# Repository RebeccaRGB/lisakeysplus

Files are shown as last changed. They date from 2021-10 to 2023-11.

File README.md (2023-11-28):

# LisaKeysPlus
This repository contains a project to create a modern replacement PCB for Apple Lisa keyboards.

The Apple Lisa used a Keytronic foam and foil keyboard which is notorious for the foam turning to dust rendering the keyboard unusable. Even after replacing the foam, I was unable to get my Lisa keyboard fully working, so instead I created a replacement PCB so I could use modern keyswitches.

This repository is still a work in progress. The timing on the keyboard controller code still needs adjusting, and the PCB may require further revisions. For example, I only recently added stabilizers to the board. If you downloaded the PCB designs before 28 November 2023, you will want to download them again to get stabilizers and a better fitting PCB. Otherwise your keys won't be stable and you'll need to expand some of the holes with a Dremel.

## Stuff To Get
* 76x Cherry MX compatible keyswitches
* 76x through-hole 1N4148 diodes
* 1x through-hole 3mm LED
* 1x through-hole 150 ohm resistor
* 2x through-hole 3-pin 2.54mm-spacing male headers
* 2x through-hole 14-pin 2.54mm-spacing male headers
* 1x through-hole 5-pin 2.54mm-spacing male header
* 1x Adafruit ItsyBitsy 32u4 5V microcontroller
* 1x 2-pin jumper
* 6x 2u stabilizers
* 1x 6.5u stabilizer (good luck; you will most likely need to get a 7u stabilizer and shorten it)

## Stuff to Make
* 1x keyboard matrix PCB, made from the Gerber files in the `gerber` directory
* 4x mounting brackets, 3D printed from the STL file in the `mounting-bracket` directory
* a set of keycaps, made from the templates in the `keycaps` directory (more details needed)
    * The hardest to get will be the 6.5u spacebar and the 1.5u backspace. Max Keyboards will make custom sets with a 6.5u spacebar. I haven't found a source for 1.5u backspace yet. You can use a 1.5u backslash key, but the profile will be wrong.
    * You will need a 1u backslash key.
    * The 1.75u return key can be made from a 1.75u caps lock key.
    * You will need two 2.25u shift keys instead of a 2.25u shift key and a 2.75u shift key.
    * For the bottom row, in addition to the 6.5u spacebar, you will need two 1u option keys, a 2u command key, and a 2u enter key. (The original keyboard had 1.5u command and enter keys and a 7.5u spacebar, but I shortened the spacebar to at least something obtainable.)
    * Instead of num lock, /, *, -, and 2u tall +, the Lisa has clear, -, +, *, /, and comma, all 1u. Additionally, the +, *, /, and comma keys have a unique style of directional arrows on the bottom half of the key.

## Stuff to Do
* Program the ItsyBitsy microcontroller with the Arduino sketch in the `lisakeysplus` directory
* Solder in the diodes **first**
* Solder in the LED in the desired location near the caps lock key
* Solder in the resistor and headers
* Solder in the ItsyBitsy microcontroller
* Solder in the keyswitches **last**
* Add the jumper between VCC and TIP on the header above the microcontroller
* Attach the stabilizers
* Install the keycaps
* Install the four mounting brackets in the bottom of the keyboard case
* Attach the keyboard cable to the header on the top left of the board
* Assemble the keyboard case

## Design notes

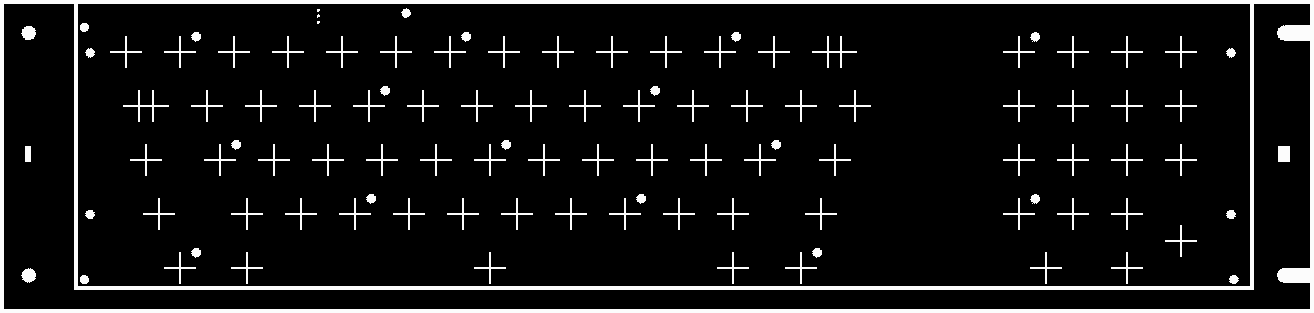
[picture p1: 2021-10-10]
fritzing/LisaKeysPlusI.png

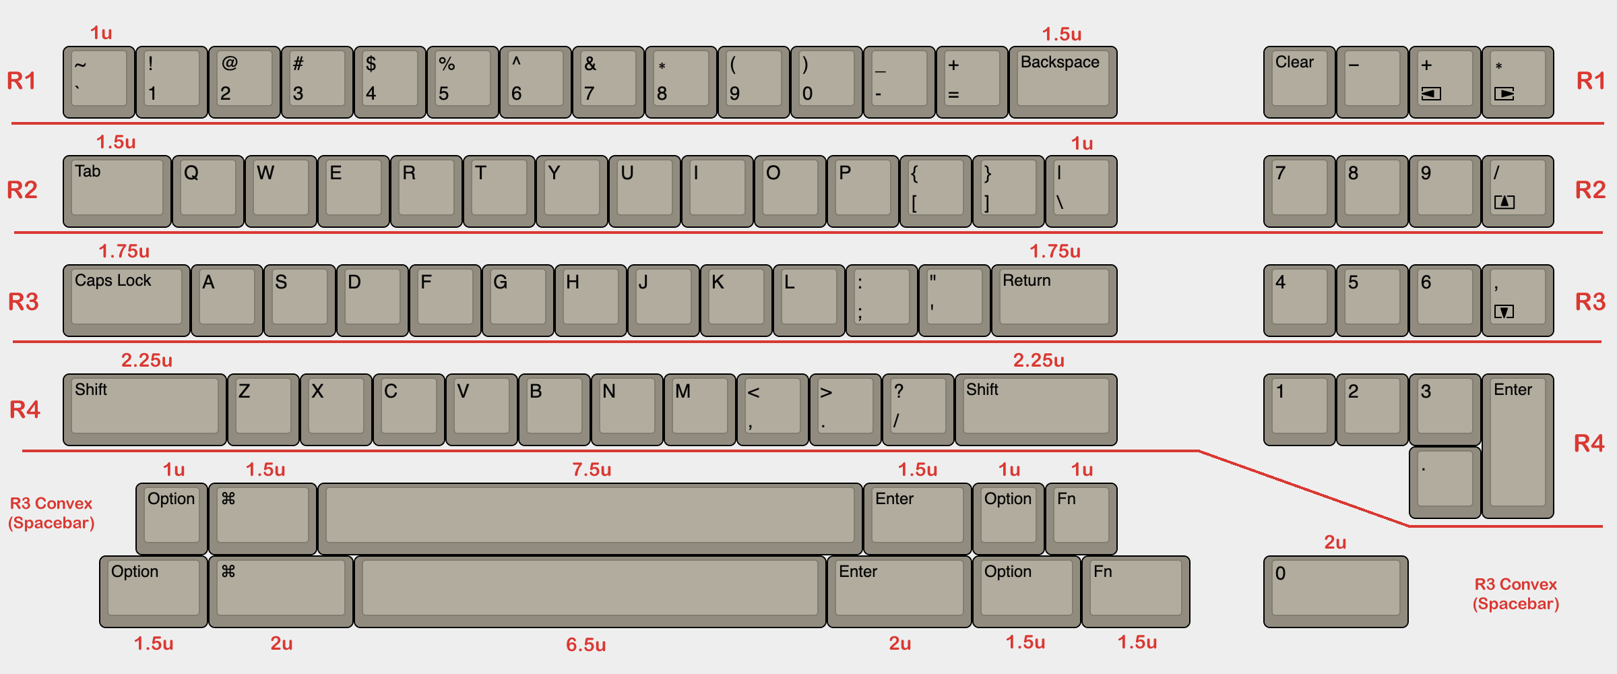
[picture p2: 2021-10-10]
keycaps/Lisa-keycaps.png

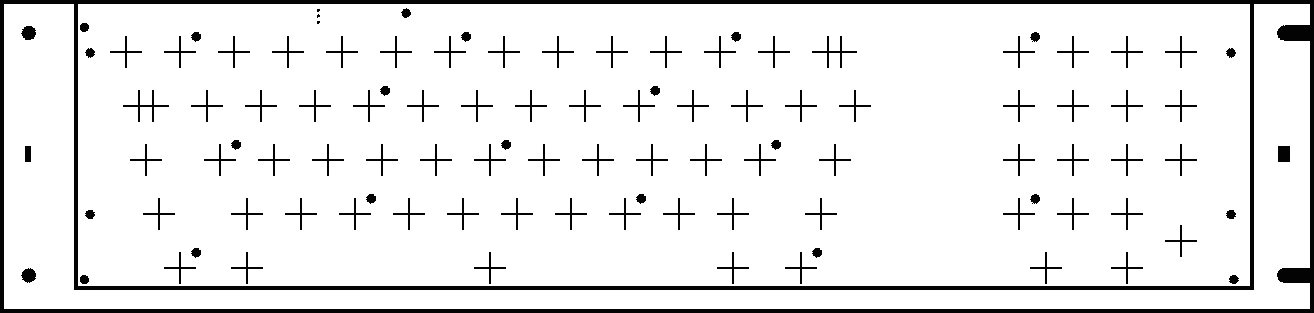
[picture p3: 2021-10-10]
fritzing/LisaKeysPlus.png

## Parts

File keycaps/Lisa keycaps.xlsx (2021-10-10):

Row | Size | Top | Bot | SP
R1 | 1u | ~ | ` | Dual R1C16 ~ `
R1 | 1u | ! | 1 | Dual R1C1 ! 1
R1 | 1u | @ | 2 | Dual R1C2 @ 2
R1 | 1u | # | 3 | Dual R1C3 # 3
R1 | 1u | $ | 4 | Dual R1C4 $ 4
R1 | 1u | % | 5 | Dual R1C5 % 5
R1 | 1u | ^ | 6 | Dual R1C6 ^ 6
R1 | 1u | & | 7 | Dual R1C7 & 7
R1 | 1u | * | 8 | Dual R1C8 * 8
R1 | 1u | ( | 9 | Dual R1C9 ( 9
R1 | 1u | ) | 0 | Dual R1C10 ) 0
R1 | 1u | _ | - | Dual R1C11 _ -
R1 | 1u | + | = | Dual R1C12 + =
R1 | 1.5u | Backspace |  | Text BACKSPACE
R2 | 1.5u | Tab |  | Text TAB
R2 | 1u | Q |  | Mono 5J
R2 | 1u | W |  | Mono 5P
R2 | 1u | E |  | Mono 4O
R2 | 1u | R |  | Mono 5K
R2 | 1u | T |  | Mono 5M
R2 | 1u | Y |  | Mono 6A
R2 | 1u | U |  | Mono 5N
R2 | 1u | I |  | Mono 5B
R2 | 1u | O |  | Mono 5H
R2 | 1u | P |  | Mono 5I
R2 | 1u | { | [ | Dual R1C13 { [
R2 | 1u | } | ] | Dual R1C14 } ]
R2 | 1u | | | \ | Dual R1C15 | \
R3 | 1.75u | Caps Lock |  | Text CAPS LOCK
R3 | 1u | A |  | Mono 4K
R3 | 1u | S |  | Mono 5L
R3 | 1u | D |  | Mono 4N
R3 | 1u | F |  | Mono 4P
R3 | 1u | G |  | Mono 4Q
R3 | 1u | H |  | Mono 5A
R3 | 1u | J |  | Mono 5C
R3 | 1u | K |  | Mono 5D
R3 | 1u | L |  | Mono 5E
R3 | 1u | : | ; | Dual R1C17 : ;
R3 | 1u | " | ' | Dual R2C1 " '
R3 | 1.75u | Return |  | Text RETURN
R4 | 2.25u | Shift |  | Text SHIFT
R4 | 1u | Z |  | Mono 6B
R4 | 1u | X |  | Mono 5Q
R4 | 1u | C |  | Mono 4M
R4 | 1u | V |  | Mono 5O
R4 | 1u | B |  | Mono 4L
R4 | 1u | N |  | Mono 5G
R4 | 1u | M |  | Mono 5F
R4 | 1u | < | , | Dual R2C2 < ,
R4 | 1u | > | . | Dual R2C3 > .
R4 | 1u | ? | / | Dual R2C4 ? /
R4 | 2.25u | Shift |  | Text SHIFT
Space Bar | 1u | Option |  | Text OPTION
Space Bar | 1.5u | ⌘ |  | Icon A8
Space Bar | 7.5u |  |  | Blank
Space Bar | 1.5u | Enter |  | Text ENTER
Space Bar | 1u | Option |  | Text OPTION
Space Bar | 1u | Fn |  | Text FN
Space Bar | 1.5u | Option |  | Text OPTION
Space Bar | 2u | ⌘ |  | Icon A8
Space Bar | 6.5u |  |  | Blank
Space Bar | 2u | Enter |  | Text ENTER
Space Bar | 1.5u | Option |  | Text OPTION
Space Bar | 1.5u | Fn |  | Text FN
R1 | 1u | Clear |  | Text CLEAR
R1 | 1u | - |  | Mono 1F
R1 | 1u | + |  | numpad-arrow-keys-sp.ai R1C1
R1 | 1u | * |  | numpad-arrow-keys-sp.ai R1C2
R2 | 1u | 7 |  | Mono 4F
R2 | 1u | 8 |  | Mono 4G
R2 | 1u | 9 |  | Mono 4H
R2 | 1u | / |  | numpad-arrow-keys-sp.ai R2C2
R3 | 1u | 4 |  | Mono 4C
R3 | 1u | 5 |  | Mono 4D
R3 | 1u | 6 |  | Mono 4E
R3 | 1u | , |  | numpad-arrow-keys-sp.ai R3C2
R4 | 1u | 1 |  | Mono 3Q
R4 | 1u | 2 |  | Mono 4A
R4 | 1u | 3 |  | Mono 4B
R4 | Num Enter | Enter |  | Text ENTER
Space Bar | 2u | 0 |  | Mono 4I
R4 | 1u | . |  | Mono 2A

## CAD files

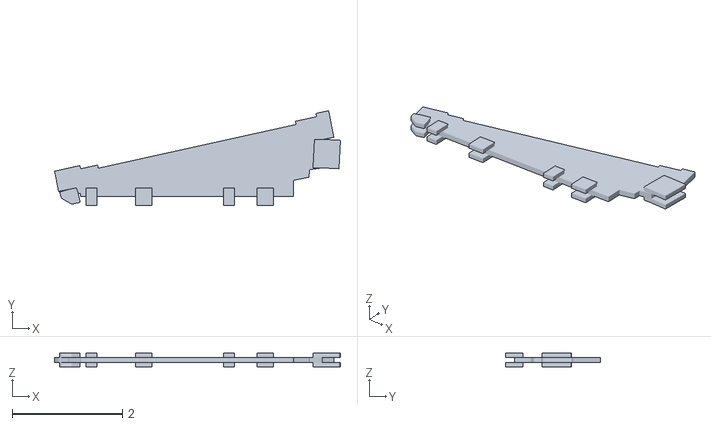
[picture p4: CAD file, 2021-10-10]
mounting-bracket/lkbracket.stl
5.19 x 1.72 x 0.256

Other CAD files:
mounting-bracket/lkbracket.skp

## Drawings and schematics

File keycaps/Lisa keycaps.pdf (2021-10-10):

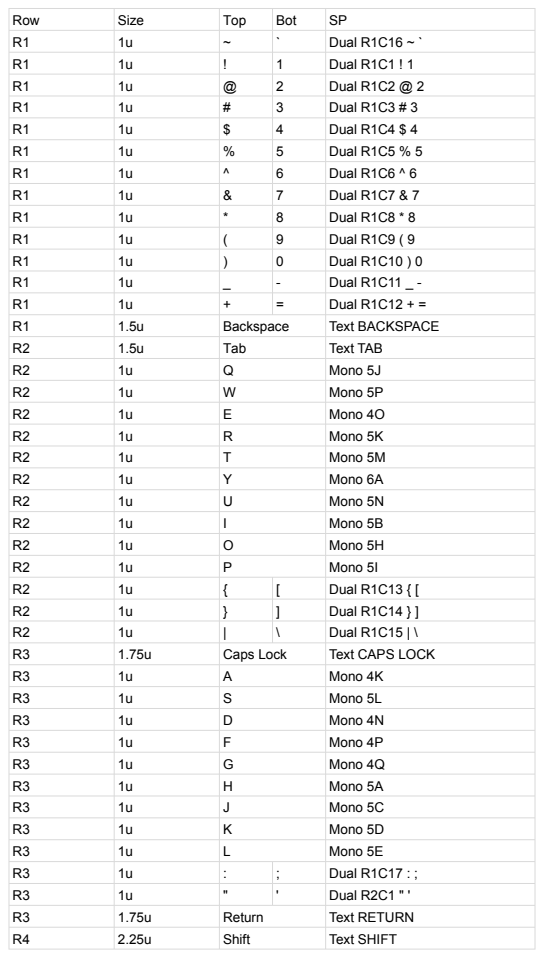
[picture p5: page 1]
Row; Size; Top; Bot; Dual R1C16 ~ `; Dual R1C1 ! 1; Dual R1C2 @ 2; Dual R1C3 # 3; Dual R1C4 $ 4; Dual R1C5 % 5; Dual R1C6 ^ 6; Dual R1C7 & 7; Dual R1C8 * 8; Dual R1C9 ( 9; Dual R1C10 ) 0; Dual R1C11 _ -; Dual R1C12 + =; Backspace; Text BACKSPACE; Tab; Text TAB; Mono 5J; Mono 5P; Mono 4O; Mono 5K; Mono 5M; Mono 6A; Mono 5N; Mono 5B; Mono 5H; Mono 5I; Dual R1C13 { [; Dual R1C14 } ]; Dual R1C15 | \; Caps Lock; Text CAPS LOCK; Mono 4K; Mono 5L; Mono 4N; Mono 4P; Mono 4Q; Mono 5A; Mono 5C; Mono 5D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

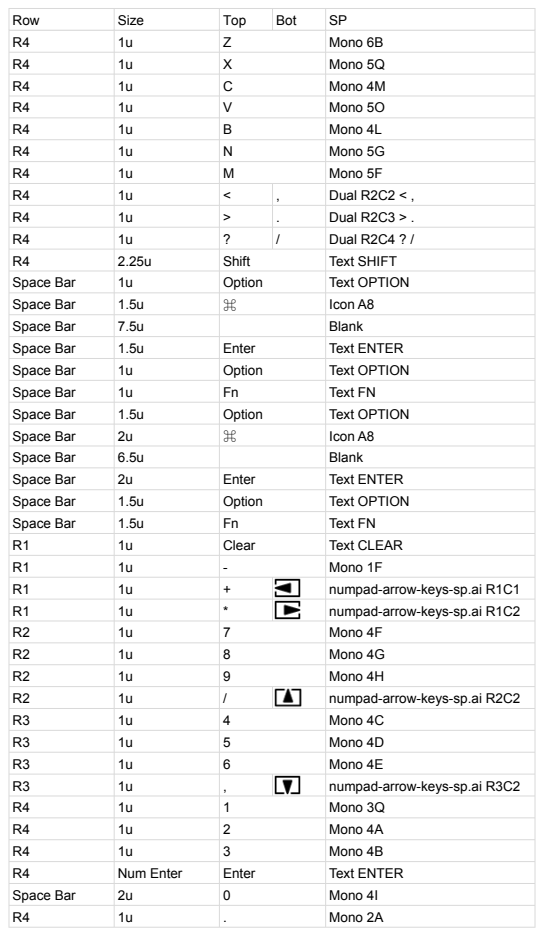
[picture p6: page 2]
Row; Size; Top; Bot; Mono 6B; Mono 5Q; Mono 4M; Mono 5O; Mono 4L; Mono 5G; Mono 5F; Dual R2C2 < ,; Dual R2C3 > .; Dual R2C4 ? /; Shift; Text SHIFT; Space Bar; Option; Text OPTION; Icon A8; Blank; Enter; Text ENTER; Text FN; Clear; Text CLEAR; Mono 1F; numpad-arrow-keys-sp.ai R1C1; numpad-arrow-keys-sp.ai R1C2; Mono 4F; Mono 4G; Mono 4H; numpad-arrow-keys-sp.ai R2C2; Mono 4C; Mono 4D; Mono 4E; numpad-arrow-keys-sp.ai R3C2; Mono 3Q; Mono 4A; Mono 4B; Num Enter; Mono 4I; Mono 2A

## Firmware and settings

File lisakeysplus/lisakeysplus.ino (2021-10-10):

#include <Arduino.h>
#include <avr/pgmspace.h>
#include <util/delay.h>
#include "matrixconfig.h"
#include "matrix.h"
#include "translateconfig.h"
#include "translate.h"
#include "lisaconfig.h"
#include "lisa.h"

void setup() {
  matrix_init();
  translate_init();
  lk_init(LK_LAYOUT_US);
#ifdef LK_DEBUG
  Serial.begin(9600);
#endif
}

void loop() {
  char packet = matrix_read_packet();
  if (packet != -1) {
    packet = translate_packet(packet);
    if (packet != 0) {
      lk_write(packet);
#ifdef LK_DEBUG
      Serial.print(packet & 0xFF, HEX);
      Serial.print(" ");
      Serial.println(lk_key_name(packet));
#endif
    }
  }
  lk_flush();
}

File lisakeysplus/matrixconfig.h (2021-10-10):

#ifndef MATRIXCONFIG_H
#define MATRIXCONFIG_H

// ItsyBitsy 32u4 A1
#define MTX_CATHODE_1_DDR  DDRF
#define MTX_CATHODE_1_PORT PORTF
#define MTX_CATHODE_1_PIN  PINF
#define MTX_CATHODE_1_MASK (1<<6)

// ItsyBitsy 32u4 A3
#define MTX_CATHODE_2_DDR  DDRF
#define MTX_CATHODE_2_PORT PORTF
#define MTX_CATHODE_2_PIN  PINF
#define MTX_CATHODE_2_MASK (1<<4)

// ItsyBitsy 32u4 A5
#define MTX_CATHODE_3_DDR  DDRF
#define MTX_CATHODE_3_PORT PORTF
#define MTX_CATHODE_3_PIN  PINF
#define MTX_CATHODE_3_MASK (1<<0)

// ItsyBitsy 32u4 SCK
#define MTX_CATHODE_4_DDR  DDRB
#define MTX_CATHODE_4_PORT PORTB
#define MTX_CATHODE_4_PIN  PINB
#define MTX_CATHODE_4_MASK (1<<1)

// ItsyBitsy 32u4 MOSI
#define MTX_CATHODE_5_DDR  DDRB
#define MTX_CATHODE_5_PORT PORTB
#define MTX_CATHODE_5_PIN  PINB
#define MTX_CATHODE_5_MASK (1<<2)

// ItsyBitsy 32u4 A4
#define MTX_CATHODE_6_DDR  DDRF
#define MTX_CATHODE_6_PORT PORTF
#define MTX_CATHODE_6_PIN  PINF
#define MTX_CATHODE_6_MASK (1<<1)

// ItsyBitsy 32u4 A2
#define MTX_CATHODE_7_DDR  DDRF
#define MTX_CATHODE_7_PORT PORTF
#define MTX_CATHODE_7_PIN  PINF
#define MTX_CATHODE_7_MASK (1<<5)

// ItsyBitsy 32u4 A0
#define MTX_CATHODE_8_DDR  DDRF
#define MTX_CATHODE_8_PORT PORTF
#define MTX_CATHODE_8_PIN  PINF
#define MTX_CATHODE_8_MASK (1<<7)

// ItsyBitsy 32u4 D11
#define MTX_ANODE_A_DDR  DDRB
#define MTX_ANODE_A_PORT PORTB
#define MTX_ANODE_A_PIN  PINB
#define MTX_ANODE_A_MASK (1<<7)

// ItsyBitsy 32u4 D9
#define MTX_ANODE_B_DDR  DDRB
#define MTX_ANODE_B_PORT PORTB
#define MTX_ANODE_B_PIN  PINB
#define MTX_ANODE_B_MASK (1<<5)

// ItsyBitsy 32u4 D7
#define MTX_ANODE_C_DDR  DDRE
#define MTX_ANODE_C_PORT PORTE
#define MTX_ANODE_C_PIN  PINE
#define MTX_ANODE_C_MASK (1<<6)

// ItsyBitsy 32u4 D10
#define MTX_ANODE_D_DDR  DDRB
#define MTX_ANODE_D_PORT PORTB
#define MTX_ANODE_D_PIN  PINB
#define MTX_ANODE_D_MASK (1<<6)

// ItsyBitsy 32u4 D12
#define MTX_ANODE_E_DDR  DDRD
#define MTX_ANODE_E_PORT PORTD
#define MTX_ANODE_E_PIN  PIND
#define MTX_ANODE_E_MASK (1<<6)

// ItsyBitsy 32u4 D2/SDA
#define MTX_ANODE_F_DDR  DDRD
#define MTX_ANODE_F_PORT PORTD
#define MTX_ANODE_F_PIN  PIND
#define MTX_ANODE_F_MASK (1<<1)

// ItsyBitsy 32u4 D3/SCL
#define MTX_ANODE_G_DDR  DDRD
#define MTX_ANODE_G_PORT PORTD
#define MTX_ANODE_G_PIN  PIND
#define MTX_ANODE_G_MASK (1<<0)

// ItsyBitsy 32u4 D4
#define MTX_ANODE_H_DDR  DDRD
#define MTX_ANODE_H_PORT PORTD
#define MTX_ANODE_H_PIN  PIND
#define MTX_ANODE_H_MASK (1<<4)

// ItsyBitsy 32u4 D6
#define MTX_ANODE_J_DDR  DDRD
#define MTX_ANODE_J_PORT PORTD
#define MTX_ANODE_J_PIN  PIND
#define MTX_ANODE_J_MASK (1<<7)

// ItsyBitsy 32u4 D8
#define MTX_ANODE_K_DDR  DDRB
#define MTX_ANODE_K_PORT PORTB
#define MTX_ANODE_K_PIN  PINB
#define MTX_ANODE_K_MASK (1<<4)

#endif

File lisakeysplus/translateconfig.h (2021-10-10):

#ifndef TRANSLATECONFIG_H
#define TRANSLATECONFIG_H

// ItsyBitsy 32u4 D13
#define TR_LED_DDR  DDRC
#define TR_LED_PORT PORTC
#define TR_LED_PIN  PINC
#define TR_LED_MASK (1<<7)

#define MTX_CAPS_LOCK   0x0A
#define MTX_LEFT_SHIFT  0x0B
#define MTX_RIGHT_SHIFT 0x2C

#endif
